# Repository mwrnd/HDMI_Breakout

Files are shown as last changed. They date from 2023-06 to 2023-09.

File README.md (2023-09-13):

**Work-In-Progress**: [Gerbers produced](https://github.com/mwrnd/HDMI_Breakout/releases/tag/v0.1-alpha) and awaiting testing.

# HDMI Breakout

[HDMI](https://en.wikipedia.org/wiki/HDMI) to [U.FL/UMCC Connector](https://en.wikipedia.org/wiki/Hirose_U.FL) breakout.

[hdmi_pmod](https://github.com/adwranovsky/hdmi_pmod) is a similar project but with a [PMOD](https://en.wikipedia.org/wiki/Pmod_Interface) interface.

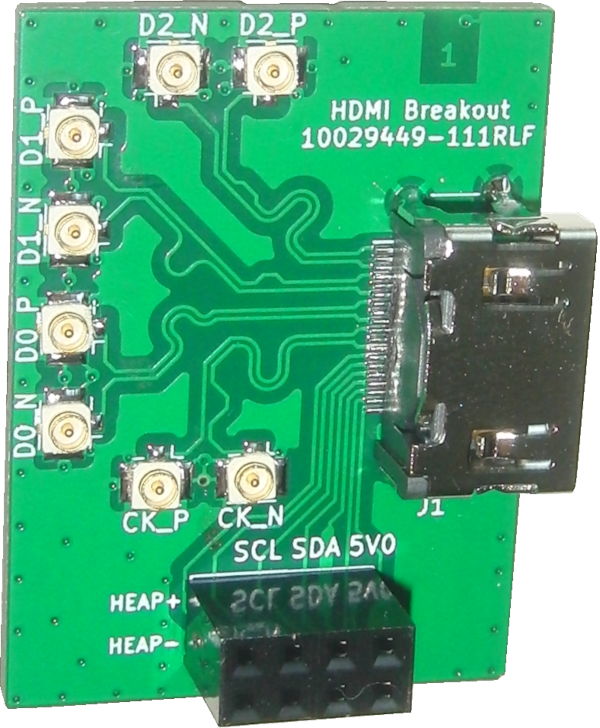
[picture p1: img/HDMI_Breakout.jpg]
HDMI Breakout PCB


# PCB Layout

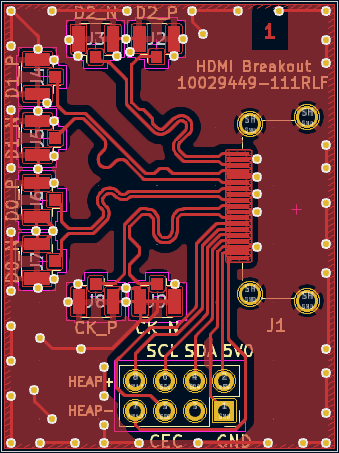
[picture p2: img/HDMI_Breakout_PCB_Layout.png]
HDMI Breakout PCB Layout


All differential signals are length-matched to within 1mm, both inter-pair and intra-pair.

I used the KiCad-included symbol and footprint for the [10029449-111RLF](https://www.digikey.com/en/products/detail/amphenol-cs-fci/10029449-111RLF/2785386). The U.FL/UMCC connectors can be [CONUFL001-SMD-T](https://www.trustedparts.com/en/search/CONUFL001-SMD-T) or [U.FL-R-SMT](https://www.trustedparts.com/en/search/U.FL-R-SMT).

# Schematic

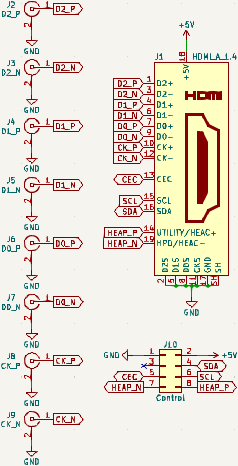
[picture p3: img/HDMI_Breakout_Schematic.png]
HDMI Breakout Schematic


# PCB Layer Stackup

4-Layer PCB stackup taken from [JLCPCB](https://jlcpcb.com/capabilities/pcb-capabilities).

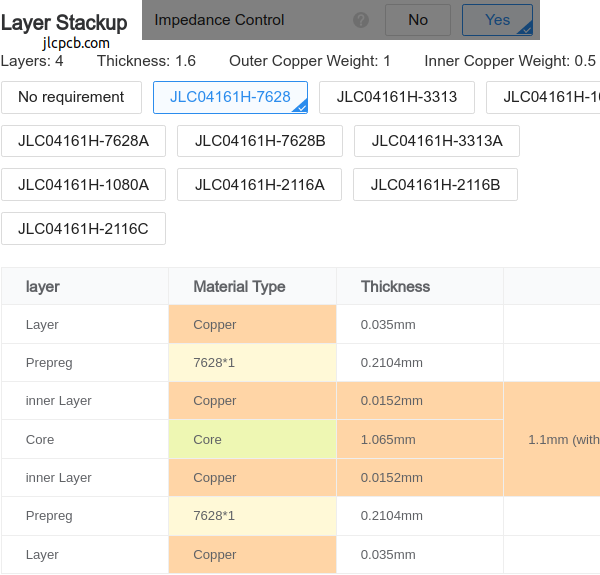
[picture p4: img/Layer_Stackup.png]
PCB Layer Stackup


100-ohm Differential Impedance parameters were calculated using the [DigiKey Online Calculator](https://www.digikey.com/en/resources/conversion-calculators/conversion-calculator-pcb-trace-impedance).

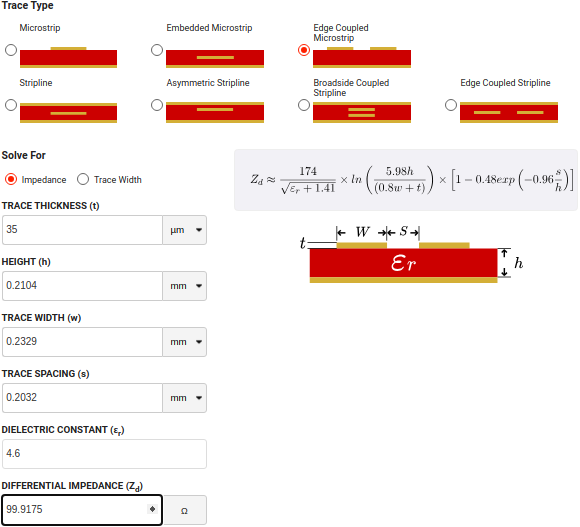
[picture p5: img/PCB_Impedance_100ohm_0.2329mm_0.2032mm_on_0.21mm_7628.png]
PCB Differential Impedance Calculation


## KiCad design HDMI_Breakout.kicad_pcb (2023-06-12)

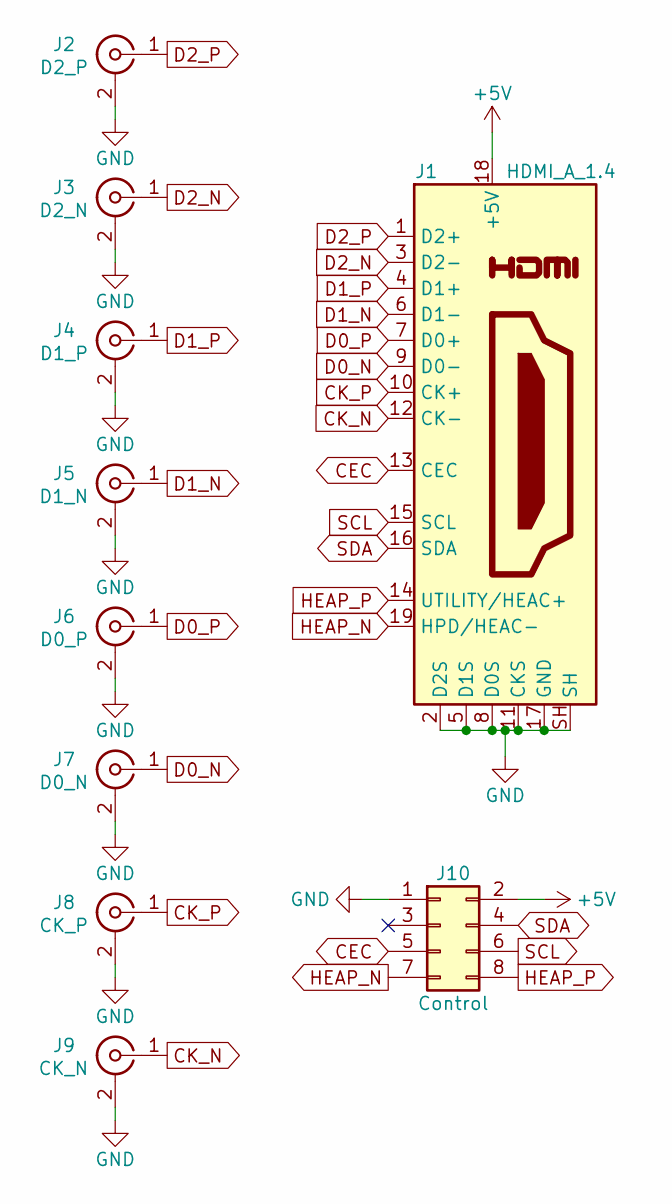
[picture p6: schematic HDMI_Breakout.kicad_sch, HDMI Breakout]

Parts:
J1: HDMI_A_1.4; HDMI_A_Amphenol_10029449-x01xLF_Horizontal
J2: D2_P; U.FL_Hirose_w_Label
J3: D2_N; U.FL_Hirose_w_Label
J4: D1_P; U.FL_Hirose_w_Label
J5: D1_N; U.FL_Hirose_w_Label
J6: D0_P; U.FL_Hirose_w_Label
J7: D0_N; U.FL_Hirose_w_Label
J8: CK_P; U.FL_Hirose_w_Label
J9: CK_N; U.FL_Hirose_w_Label
J10: Control; PinSocket_2x04_P2.54mm_Vertical

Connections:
+5V: J1.18 (+5V), J10.2
CEC: J1.13 (CEC), J10.5
CK_N: J1.12 (CK-), J9.1 (In)
CK_P: J1.10 (CK+), J8.1 (In)
D0_N: J1.9 (D0-), J7.1 (In)
D0_P: J1.7 (D0+), J6.1 (In)
D1_N: J1.6 (D1-), J5.1 (In)
D1_P: J1.4 (D1+), J4.1 (In)
D2_N: J1.3 (D2-), J3.1 (In)
D2_P: J1.1 (D2+), J2.1 (In)
GND: J1.2 (D2S), J1.5 (D1S), J1.8 (D0S), J1.11 (CKS), J1.17 (GND), J1.SH, J2.2 (Ext), J3.2 (Ext), J4.2 (Ext), J5.2 (Ext), J6.2 (Ext), J7.2 (Ext), J8.2 (Ext), J9.2 (Ext), J10.1
HEAP_N: J1.19 (HPD/HEAC-), J10.7
HEAP_P: J1.14 (UTILITY/HEAC+), J10.8
SCL: J1.15 (SCL), J10.6
SDA: J1.16 (SDA), J10.4

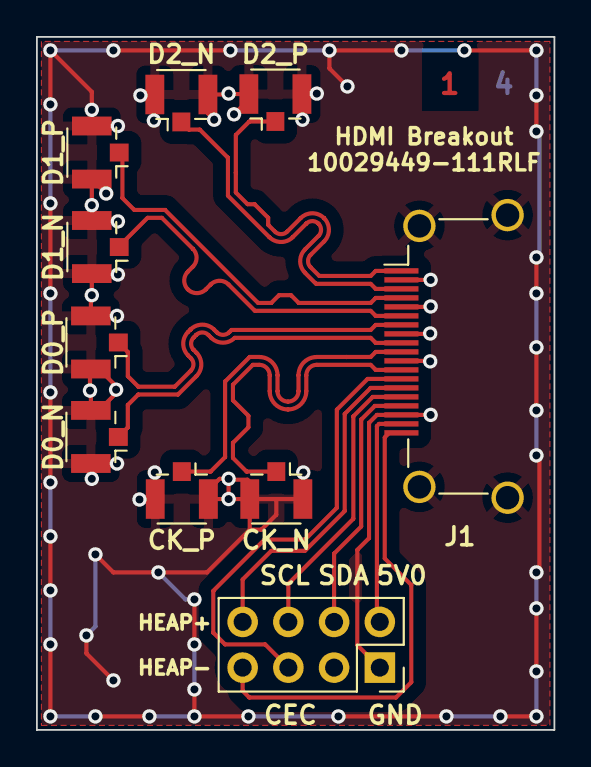
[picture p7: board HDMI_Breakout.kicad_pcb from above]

Board: 4 copper layers, 28.8 x 38.5 mm, 10 parts (0 on the bottom side), 15 nets.
